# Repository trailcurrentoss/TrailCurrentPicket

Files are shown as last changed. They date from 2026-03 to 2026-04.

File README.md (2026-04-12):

# TrailCurrent Picket

Sensor module that monitors cabinet and door open/closed states using reed switches and reports status over a CAN bus interface. Part of the [TrailCurrent](https://trailcurrent.com) open-source vehicle platform.

## Hardware Overview

- **Board:** [Waveshare ESP32-S3-RS485-CAN](https://www.waveshare.com/esp32-s3-rs485-can.htm)
- **Microcontroller:** ESP32-S3
- **Framework:** ESP-IDF
- **Function:** Cabinet and door state monitoring with CAN bus reporting
- **Key Features:**
  - 13 reed switch inputs for open/closed detection
  - CAN bus communication at 500 kbps (onboard TJA1051 transceiver)
  - Firmware-configurable CAN address via NVS (up to 8 modules per bus)
  - Over-the-air (OTA) firmware updates via WiFi (triggered over CAN)
  - Onboard status LED
  - Custom flash partition layout with dual OTA slots

### Design Specifications

- **Operating Temperature:** -20°C to +70°C
- **Power:** 7-36V DC input via onboard buck converter
- **Data Rate:** 5 transmissions per second

## CAN Bus Addressing

The CAN message ID is set at compile time via the `PICKET_ADDRESS` build flag. Valid values are **0 through 7**, giving 8 possible modules on the same bus. The CAN ID is computed as `0x0A + PICKET_ADDRESS`. Default is 0 if not specified. The build will fail if a value outside 0-7 is used.

```bash
# Build with default address 0 (CAN ID 0x0A)
idf.py build

# Build for address 3 (CAN ID 0x0D)
idf.py build -DPICKET_ADDRESS=3
```

| `PICKET_ADDRESS` | CAN ID | DBC Message Name |
|---|---|---|
| 0 (default) | 0x0A | PicketStatus0 |
| 1 | 0x0B | PicketStatus1 |
| 2 | 0x0C | PicketStatus2 |
| 3 | 0x0D | PicketStatus3 |
| 4 | 0x0E | PicketStatus4 |
| 5 | 0x0F | PicketStatus5 |
| 6 | 0x10 | PicketStatus6 |
| 7 | 0x11 | PicketStatus7 |

#### Building All Variants

Use `build-all.sh` to build all 8 address variants in a single run:

```bash
./build-all.sh
```

This produces:

```
build/picket_addr0.bin   # Address 0 (CAN ID 0x0A)
build/picket_addr1.bin   # Address 1 (CAN ID 0x0B)
...
build/picket_addr7.bin   # Address 7 (CAN ID 0x11)
```

#### Creating a GitHub Release

After building all variants, upload all 8 binaries as release assets:

```bash
git tag -a v1.0.0 -m "Firmware release v1.0.0"
git push origin v1.0.0

gh release create v1.0.0 \
  build/picket_addr0.bin \
  build/picket_addr1.bin \
  build/picket_addr2.bin \
  build/picket_addr3.bin \
  build/picket_addr4.bin \
  build/picket_addr5.bin \
  build/picket_addr6.bin \
  build/picket_addr7.bin \
  --repo trailcurrentoss/TrailCurrentPicket \
  --title "v1.0.0" \
  --notes "Firmware release v1.0.0"
```

The Headwaters deployment system and the web-based firmware installer both expect these 8 files per release. The naming convention `{type}_addr{N}.bin` is required.

### CAN Message Format

Each module transmits a 2-byte message at 5 Hz (200 ms interval):

| Byte | Bits  | Description |
|---|---|---|
| 0 | 0-7 | Door status 1-8 (RSW01-RSW08) |
| 1 | 0-4 | Door status 9-13 (RSW09-RSW13) |
| 1 | 5-7 | Reserved |

Each bit represents one reed switch: `1` = door open, `0` = door closed.

### CAN Control Messages

The module also listens for control messages from other nodes:

- **CAN ID 0x00 - OTA Update Notification:** Contains a 3-byte MAC address suffix. If it matches this module's hostname, the module connects to WiFi using stored credentials and enters OTA update mode.
- **CAN ID 0x01 - WiFi Credential Configuration:** Multi-message protocol to receive and store WiFi SSID and password in NVS flash for future OTA updates.
- **CAN ID 0x02 - Discovery Trigger:** Broadcast with no payload. Unconfigured modules respond by joining WiFi and advertising via mDNS for Headwaters to discover and register them.
- **CAN ID 0x03 - Discovery Reset:** Targeted by MAC address. Clears the configured flag so the module responds to the next discovery trigger.
- **CAN ID 0x04 - Firmware Version Report:** Sent once on boot. Payload: `[mac3, mac4, mac5, major, minor, patch]`. Reports running firmware version to Headwaters.

### Module Discovery

New modules are automatically discovered by Headwaters using a one-at-a-time registration protocol:

1. Headwaters sends CAN ID 0x02 (broadcast, no payload)
2. Unconfigured modules join WiFi and advertise `_trailcurrent._tcp` via mDNS with TXT records: `type`, `addr`, `canid`, `fw`
3. Headwaters browses mDNS, reads the metadata, and sends `GET /discovery/confirm`
4. Module marks itself configured in NVS and tears down WiFi

The discovery window is 30 seconds. The status LED blinks at 4 Hz during discovery. Already-configured modules ignore the trigger. To re-discover a module, send CAN ID 0x03 with its MAC bytes to clear the configured flag.

### Firmware Version

The firmware version is set in `CMakeLists.txt` via `PROJECT_VER` and reported during discovery via the `fw` mDNS TXT record. It is also available at runtime via `esp_app_get_description()`.

## GPIO Pin Assignments

### Onboard (not on pin header)

| GPIO | Function | Notes |
|---|---|---|
| 0 | Status LED | Onboard LED |
| 15 | CAN TX | Onboard TJA1051 transceiver |
| 16 | CAN RX | Onboard TJA1051 transceiver |
| 19 | USB D_N | USB Serial/JTAG (flash + monitor) |
| 20 | USB D_P | USB Serial/JTAG (flash + monitor) |

### Pin Header (reed switch inputs)

| GPIO | Function | Notes |
|---|---|---|
| 4 | RSW01 | Internal pull-up, no ext. resistor |
| 5 | RSW02 | Internal pull-up, no ext. resistor |
| 6 | RSW03 | Internal pull-up, no ext. resistor |
| 7 | RSW04 | Internal pull-up, no ext. resistor |
| 8 | RSW05 | Internal pull-up, no ext. resistor |
| 9 | RSW06 | Internal pull-up, no ext. resistor |
| 10 | RSW07 | Internal pull-up, no ext. resistor |
| 11 | RSW08 | Internal pull-up, no ext. resistor |
| 12 | RSW09 | Internal pull-up, no ext. resistor |
| 13 | RSW10 | Internal pull-up, no ext. resistor |
| 14 | RSW11 | Internal pull-up, no ext. resistor |
| 43 | RSW12 | Internal pull-up, no ext. resistor |
| 44 | RSW13 | Internal pull-up, no ext. resistor |

## Hardware Requirements

### Components

- **Board:** [Waveshare ESP32-S3-RS485-CAN](https://www.waveshare.com/esp32-s3-rs485-can.htm) — industrial-grade board with onboard CAN transceiver, buck converter (7-36V input), and pin header for sensor connections
- **Sensors:** Normally Open (NO) reed switches
- **Connectors:** Wire to pin header (2x10, 2.54mm pitch)

### KiCAD Library Dependencies

This project uses the consolidated [TrailCurrentKiCADLibraries](https://github.com/trailcurrentoss/TrailCurrentKiCADLibraries).

**Setup:**

```bash
# Clone the library alongside this project
git clone git@github.com:trailcurrentoss/TrailCurrentKiCADLibraries.git

# Set environment variables (add to ~/.bashrc or ~/.zshrc)
# Adjust paths to where you cloned the library
export TRAILCURRENT_SYMBOL_DIR="../TrailCurrentKiCADLibraries/symbols"
export TRAILCURRENT_FOOTPRINT_DIR="../TrailCurrentKiCADLibraries/footprints"
export TRAILCURRENT_3DMODEL_DIR="../TrailCurrentKiCADLibraries/3d_models"
```

See [KICAD_ENVIRONMENT_SETUP.md](https://github.com/trailcurrentoss/TrailCurrentKiCADLibraries/blob/main/KICAD_ENVIRONMENT_SETUP.md) in the library repository for detailed setup instructions.

## Firmware

The firmware is built with ESP-IDF (not PlatformIO/Arduino).

### Build & Flash

```bash
# Source ESP-IDF environment
source ~/esp/v5.5.2/esp-idf/export.sh

# Set target (first time only)
idf.py set-target esp32s3

# Build (default address 0, CAN ID 0x0A)
idf.py build

# Build with a specific module address (0-7)
idf.py build -DPICKET_ADDRESS=3

# Flash via USB
idf.py -p /dev/ttyACM0 flash

# Monitor serial output
idf.py -p /dev/ttyACM0 monitor
```

### OTA Update

```bash
# Use the binary matching the module's address
curl -X POST http://esp32-XXYYZZ.local/ota --data-binary @build/picket_addr0.bin
```

Where `XXYYZZ` is the last 3 bytes of the device's WiFi MAC address (printed at boot).

## Opening the Project

1. **Set up environment variables** (see Library Dependencies above)
2. **Open KiCAD:**
   ```bash
   kicad EDA/TrailCurrentPicketModule/TrailCurrentPicketModule.kicad_pro
   ```
3. **Verify libraries load** - All symbol and footprint libraries should resolve without errors
4. **View 3D models** - Open PCB and press `Alt+3` to view the 3D visualization

## Manufacturing

- **PCB Files:** Ready for fabrication via standard PCB services (JLCPCB, OSH Park, etc.)
- **BOM Generation:** Export BOM from KiCAD schematic (Tools > Generate BOM)
- **Enclosure:** FreeCAD design included in `CAD/` directory
- **JLCPCB Assembly:** See [BOM_ASSEMBLY_WORKFLOW.md](https://github.com/trailcurrentoss/TrailCurrentKiCADLibraries/blob/main/BOM_ASSEMBLY_WORKFLOW.md) for detailed assembly workflow

## Documentation

- **Requirements:** See `DOCS/Requirements/high-level-requirements.md` for detailed specifications

## Project Structure

```
├── CAD/                          # FreeCAD enclosure design
├── DOCS/                         # Requirements documentation
│   └── Requirements/
│       └── high-level-requirements.md
├── EDA/                          # KiCAD hardware design files
│   └── TrailCurrentPicketModule/
│       ├── *.kicad_pro           # KiCAD project
│       ├── *.kicad_sch           # Schematic
│       └── *.kicad_pcb           # PCB layout
├── main/                         # ESP-IDF firmware source
│   ├── main.c                    # Main application, CAN task, reed switch reading
│   ├── discovery.h / discovery.c # mDNS self-discovery and Headwaters registration
│   ├── ota.h / ota.c             # OTA firmware updates via WiFi
│   ├── wifi_config.h / .c        # WiFi credential storage and CAN provisioning
│   ├── CMakeLists.txt            # Component build config
│   └── idf_component.yml         # Component dependencies
├── CMakeLists.txt                # ESP-IDF project root
├── partitions.csv                # Flash partition layout
├── build-all.sh                  # Build all 8 address variants (addr 0-7)
└── sdkconfig.defaults            # Default build configuration
```

## License

MIT License - See LICENSE file for details.

This is open source hardware. You are free to use, modify, and distribute these designs for personal or commercial purposes.

## Contributing

Improvements and contributions are welcome! Please submit issues or pull requests.

## Support

For questions about:
- **KiCAD setup:** See [KICAD_ENVIRONMENT_SETUP.md](https://github.com/trailcurrentoss/TrailCurrentKiCADLibraries/blob/main/KICAD_ENVIRONMENT_SETUP.md)
- **Assembly workflow:** See [BOM_ASSEMBLY_WORKFLOW.md](https://github.com/trailcurrentoss/TrailCurrentKiCADLibraries/blob/main/BOM_ASSEMBLY_WORKFLOW.md)

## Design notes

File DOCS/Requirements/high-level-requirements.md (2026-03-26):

# High-Level Design (HLD) Document

## 1. Project Overview

**Project Title:** Picket Module

**Description:** A microcontroller-based system that monitors the status of doors and cabinets. It will be used to make the high level system contextually aware of which doors and or cabinets are currently open or closed.

**Objective:**
To design and implement a reliable, low-power, and cost-effective microcontroller-based system for door and cabinet status monitoring that can operate autonomously and send data over the CAN bus.

---

## 2. Microcontroller Selection

**Selected Microcontroller:**
**ESP32-S3** (Waveshare ESP32-S3-RS485-CAN)
[Datasheet](https://www.espressif.com/sites/default/files/documentation/esp32-s3_datasheet_en.pdf)

**Rationale for Selection:**
- Off-the-shelf board with onboard CAN transceiver (TJA1051), buck converter (7-36V), and 20-pin header for sensor connections.
- 13 GPIOs available on pin header with internal pull-ups — no external resistors needed.
- Strong ecosystem and ESP-IDF development support.
- Shared board with Solstice module, reducing BOM complexity.

---

## 3. System Requirements

### 3.1 Functional Requirements

| Requirement | Description |
|---|---|
| Door Sensing | Read and send over CAN bus the door or cabinet status |
| Data Transmission | Send collected data to the rest of the network via CAN protocol |
| Power Management | Support for low-power modes to reduce load on installed environment |

### 3.2 Non-Functional Requirements

| Requirement | Description |
|---|---|
| Reliability | System must operate continuously without disruption indefinitely for solar installs |
| CAN Bus Data Usage | **Needs calculation to see what is available on a 500k CAN Bus.** |
| Environmental Tolerance | Operate within -20°C to +70°C |
| Cost | Target cost < $5 per unit |
---

## 4. System Architecture Overview

### 4.1 Hardware Components

| Component | Description |
|---|---|
| ESP32-S3 (Waveshare ESP32-S3-RS485-CAN) | Main microcontroller with onboard CAN transceiver |
| Reed Swith | Any brand should suffice, justt needs to provide an on/off state to trigger correctly. |

### 4.2 Software Components

| Component | Description |
|---|---|
| Main Application | Main data collection, and transmission |
| Sensor Drivers | Interface with reed switches |
| Communication Stack | CAN Bus coomunication implementation |
| OTA | Over the air update capabilities with trigger coming from CAN Bus. |

---

## 5. Communication Protocol

- **CAN Bus:** CAN Bus protocol used to transmit data  
- **Data Format:** Binary representation of each sensor status
- **Transmission Frequency:** 5 times per second to avoid delayed notification of doors changing status during travel.
---

## 6. Power Management Strategy

- **Battery:** Connected to house battery of implemented vehicle.
- **Power Supply Circuit:** 5V DC to DC buck converter with 3.3V regulator (e.g., AMS1117)  
---

## 7. Development Tools and Environment

| Tool | Description |
|---|---|
| ESP-IDF | Development framework (v5.5.2) |
| VS Code | Development IDE |
| KiCAD | EDA Design tool for schematic and PCB |
| FreeCAD | CAD tool used for enclosure design |
| Version Control | Git with GitHub for repo and source control |
| Documentation Tools | Markdown |

---

## 8. Testing and Validation

| Test Type | Description |
|---|---|
| Unit Testing | Test individual modules (e.g., sensor drivers, communication stack) |
| Integration Testing | Ensure all components work together as expected |
| Performance Testing | Measure power consumption, response time, and data accuracy |
---

## 9. Future Enhancements

- Add GPS module for location tracking  
- Support for multiple sensors (e.g., PM2.5, CO2)  
- Edge computing for local data processing  
- Integration with IoT platforms (e.g., AWS IoT, Azure IoT Hub)  
- Mobile app integration for real-time monitoring

---

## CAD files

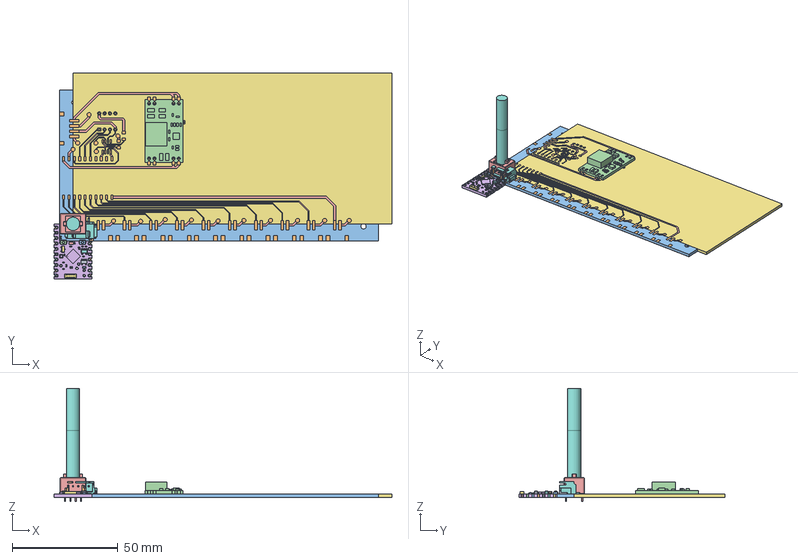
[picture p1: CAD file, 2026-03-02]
CAD/TrailCurrentPicketModuleEDA.FCStd
159.8 x 97.6 x 53.6 mm
Model-TrailCurrentCabinetAndDoorSensorModule
SxB-XH-SM4-TB
SxB-XH-SM4-TB001
SxB-XH-SM4-TB002
BODY-SO
LEAD-D0008A
LEAD-D0008A001
LEAD-D0008A002
LEAD-D0008A003
LEAD-D0008A004
LEAD-D0008A005
LEAD-D0008A006
LEAD-D0008A007
PCB
USB_C_Receptacle_16P_TopMnt_Horizontal_GCT_USB4105-xx-A037
USB_C_Receptacle_16P_TopMnt_Horizontal_GCT_USB4105-xx-A038
USB_C_Receptacle_16P_TopMnt_Horizontal_GCT_USB4105-xx-A039
USB_C_Receptacle_16P_TopMnt_Horizontal_GCT_USB4105-xx-A040
USB_C_Receptacle_16P_TopMnt_Horizontal_GCT_USB4105-xx-A041
USB_C_Receptacle_16P_TopMnt_Horizontal_GCT_USB4105-xx-A042
USB_C_Receptacle_16P_TopMnt_Horizontal_GCT_USB4105-xx-A043
USB_C_Receptacle_16P_TopMnt_Horizontal_GCT_USB4105-xx-A044
USB_C_Receptacle_16P_TopMnt_Horizontal_GCT_USB4105-xx-A045
USB_C_Receptacle_16P_TopMnt_Horizontal_GCT_USB4105-xx-A046
USB_C_Receptacle_16P_TopMnt_Horizontal_GCT_USB4105-xx-A047
USB_C_Receptacle_16P_TopMnt_Horizontal_GCT_USB4105-xx-A048
USB_C_Receptacle_16P_TopMnt_Horizontal_GCT_USB4105-xx-A049
USB_C_Receptacle_16P_TopMnt_Horizontal_GCT_USB4105-xx-A050
USB_C_Receptacle_16P_TopMnt_Horizontal_GCT_USB4105-xx-A051
USB_C_Receptacle_16P_TopMnt_Horizontal_GCT_USB4105-xx-A052
USB_C_Receptacle_16P_TopMnt_Horizontal_GCT_USB4105-xx-A053
USB_C_Receptacle_16P_TopMnt_Horizontal_GCT_USB4105-xx-A054
USB_C_Receptacle_16P_TopMnt_Horizontal_GCT_USB4105-xx-A055
USB_C_Receptacle_16P_TopMnt_Horizontal_GCT_USB4105-xx-A056
USB_C_Receptacle_16P_TopMnt_Horizontal_GCT_USB4105-xx-A057
USB_C_Receptacle_16P_TopMnt_Horizontal_GCT_USB4105-xx-A058
USB_C_Receptacle_16P_TopMnt_Horizontal_GCT_USB4105-xx-A059
USB_C_Receptacle_16P_TopMnt_Horizontal_GCT_USB4105-xx-A060
USB_C_Receptacle_16P_TopMnt_Horizontal_GCT_USB4105-xx-A061
USB_C_Receptacle_16P_TopMnt_Horizontal_GCT_USB4105-xx-A062
USB_C_Receptacle_16P_TopMnt_Horizontal_GCT_USB4105-xx-A063
USB_C_Receptacle_16P_TopMnt_Horizontal_GCT_USB4105-xx-A064
USB_C_Receptacle_16P_TopMnt_Horizontal_GCT_USB4105-xx-A065
USB_C_Receptacle_16P_TopMnt_Horizontal_GCT_USB4105-xx-A066
USB_C_Receptacle_16P_TopMnt_Horizontal_GCT_USB4105-xx-A067
USB_C_Receptacle_16P_TopMnt_Horizontal_GCT_USB4105-xx-A068
USB_C_Receptacle_16P_TopMnt_Horizontal_GCT_USB4105-xx-A069
USB_C_Receptacle_16P_TopMnt_Horizontal_GCT_USB4105-xx-A070
USB_C_Receptacle_16P_TopMnt_Horizontal_GCT_USB4105-xx-A071
USB_C_Receptacle_16P_TopMnt_Horizontal_GCT_USB4105-xx-A072
Button_black_002
Button_black_003
io23
io21
io22
io12
io13
Corps
Corps001
Corps002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

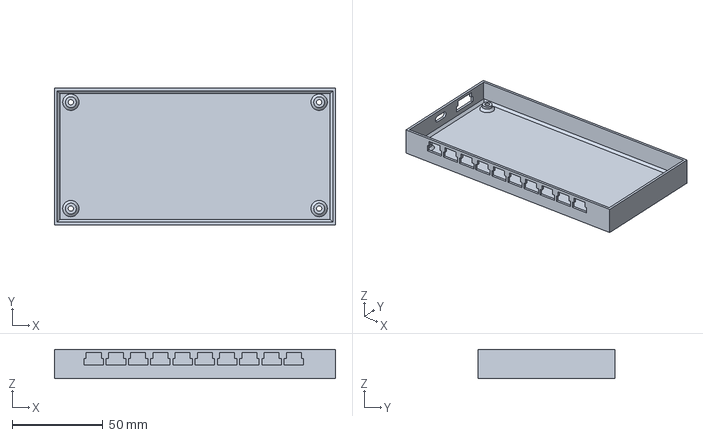
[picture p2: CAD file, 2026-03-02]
CAD/TrailCurrentPicketModuleHousing.FCStd
154.8 x 75.2 x 16.0 mm

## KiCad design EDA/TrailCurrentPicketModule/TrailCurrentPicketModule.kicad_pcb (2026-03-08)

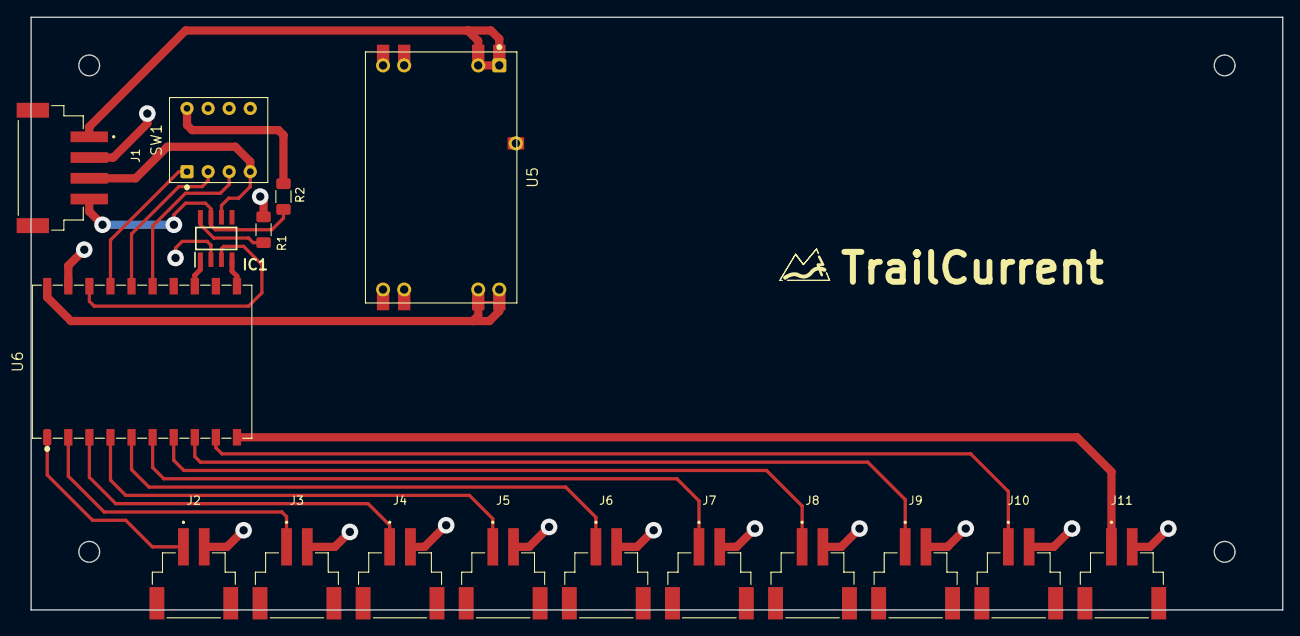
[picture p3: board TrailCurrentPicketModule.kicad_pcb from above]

Board: 2 copper layers, 150.8 x 71.4 mm, 19 parts (0 on the bottom side), 23 nets.

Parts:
IC1: SN65HVD230DR
J1: S4B-XH-SM4-TB; JST_S4B-XH-SM4-TB
J2, J3, J4, J5, J6, J7, J8, J9, J10, J11: S2B-XH-SM4-TB; JST_S2B-XH-SM4-TB
LOGO: TrailCurrentLogo_Text
LOGO#2: TrailCurrentLogo_Icon
R1: 10k; R_1206_3216Metric_Pad1.30x1.75mm_HandSolder
R2: 120; R_1206_3216Metric_Pad1.30x1.75mm_HandSolder
SW1: DS-04
U5: Mini560
U6: ESP32-C6-SuperMini; ESP32-C6-SuperMini_SMD

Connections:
+3.3V: IC1.3 (VCC), U6.13 (3V3)
+5V: U5.8 (VOUT+), U5.9 (VOUT+), U6.11 (5V)
+12V: J1.1, U5.1 (VIN+), U5.2 (VIN+)
ADDR01: SW1.3, U6.16 (GPIO18)
ADDR02: SW1.2, U6.15 (GPIO19)
ADDR03: SW1.1, U6.14 (GPIO20)
CANH: IC1.7 (CANH), J1.4, R2.1
CANL: IC1.6 (CANL), J1.3, SW1.4
CAN_RX: IC1.4 (R), U6.20 (GPIO8)
CAN_TX: IC1.1 (D), U6.18 (GPIO14)
GND: IC1.2 (GND), J1.2, J2.2, J3.2, J4.2, J5.2, J6.2, J7.2, J8.2, J9.2, J10.2, J11.2, R1.1, SW1.5, SW1.6, SW1.7, U5.3 (GND), U5.4 (GND), U5.6 (GND), U5.7 (GND), U6.12 (GND)
unnamed: IC1.8 (RS), R1.2
unnamed: R2.2, SW1.8
RSW01: J2.1, U6.1 (TX)
RSW02: J3.1, U6.2 (RX)
RSW03: J4.1, U6.3 (GPIO0)
RSW04: J5.1, U6.4 (GPIO1)
RSW05: J6.1, U6.5 (GPIO2)
RSW06: J7.1, U6.6 (GPIO3)
RSW07: J8.1, U6.7 (GPIO4)
RSW08: J9.1, U6.8 (GPIO5)
RSW09: J10.1, U6.9 (GPIO6)
RSW10: J11.1, U6.10 (GPIO7)

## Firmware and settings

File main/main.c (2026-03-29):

#include <stdio.h>
#include <string.h>
#include "freertos/FreeRTOS.h"
#include "freertos/task.h"
#include "driver/gpio.h"
#include "driver/twai.h"
#include "esp_log.h"
#include "esp_timer.h"
#include "esp_app_desc.h"
#include "esp_mac.h"
#include "wifi_config.h"
#include "ota.h"
#include "discovery.h"

static const char *TAG = "picket";

// =============================================================================
// Pin Definitions — Waveshare ESP32-S3-RS485-CAN pin header
// =============================================================================

// CAN bus pins (onboard TJA1051 transceiver, not on pin header)
#define CAN_TX_PIN   15
#define CAN_RX_PIN   16

// Status LED (onboard LED on GPIO0)
#define STATUS_LED_PIN  0

// Reed switch inputs (Normally Open — close when magnet nearby / door closed)
// HIGH = door open, LOW = door closed (using internal pull-ups)
static const gpio_num_t RSW_PINS[] = {
    GPIO_NUM_4,   // RSW01
    GPIO_NUM_5,   // RSW02
    GPIO_NUM_6,   // RSW03
    GPIO_NUM_7,   // RSW04
    GPIO_NUM_8,   // RSW05
    GPIO_NUM_9,   // RSW06
    GPIO_NUM_10,  // RSW07
    GPIO_NUM_11,  // RSW08
    GPIO_NUM_12,  // RSW09
    GPIO_NUM_13,  // RSW10
    GPIO_NUM_14,  // RSW11
    GPIO_NUM_43,  // RSW12
    GPIO_NUM_44,  // RSW13
};
#define NUM_RSW (sizeof(RSW_PINS) / sizeof(RSW_PINS[0]))

// =============================================================================
// CAN Bus Configuration
// =============================================================================

// CAN protocol IDs
#define CAN_ID_OTA              0x00
#define CAN_ID_WIFI_CONFIG      0x01
#define CAN_ID_DISCOVERY_TRIGGER 0x02

// CAN IDs 0x0A-0x11 reserved for up to 8 Picket modules.
// Set address at build time: idf.py build -DPICKET_ADDRESS=3
#define CAN_BASE_ID     0x0A
#define CAN_BAUDRATE    500000

#ifndef PICKET_ADDRESS
#define PICKET_ADDRESS  0
#endif
#if PICKET_ADDRESS < 0 || PICKET_ADDRESS > 7
#error "PICKET_ADDRESS must be 0-7"
#endif

// Transmit interval (200 ms = 5 Hz)
#define TX_INTERVAL_MS  200
#define TX_PROBE_INTERVAL_MS  2000 // slow probe when no peers detected

// Debounce time for reed switch readings
#define DEBOUNCE_MS     50

// =============================================================================
// Global State
// =============================================================================

static const uint32_t s_can_message_id = CAN_BASE_ID + PICKET_ADDRESS;

// Debounced reed switch state
static volatile uint16_t s_debounced_state = 0;

// =============================================================================
// Reed Switch Reading
// =============================================================================

static uint16_t read_reed_switches(void)
{
    uint16_t state = 0;
    for (int i = 0; i < NUM_RSW; i++) {
        // HIGH = door open (pull-up, NO reed switch open)
        // LOW = door closed (reed switch closed by magnet)
        if (gpio_get_level(RSW_PINS[i]) == 1) {
            state |= (1 << i);
        }
    }
    return state;
}

// =============================================================================
// TWAI (CAN) task — runs independently (pattern from Solstice)
// =============================================================================

static void twai_task(void *arg)
{
    twai_general_config_t g_config = TWAI_GENERAL_CONFIG_DEFAULT(
        (gpio_num_t)CAN_TX_PIN, (gpio_num_t)CAN_RX_PIN, TWAI_MODE_NORMAL);
    twai_timing_config_t t_config = TWAI_TIMING_CONFIG_500KBITS();
    twai_filter_config_t f_config = TWAI_FILTER_CONFIG_ACCEPT_ALL();

    if (twai_driver_install(&g_config, &t_config, &f_config) != ESP_OK) {
        ESP_LOGE(TAG, "Failed to install TWAI driver");
        vTaskDelete(NULL);
        return;
    }
    if (twai_start() != ESP_OK) {
        ESP_LOGE(TAG, "Failed to start TWAI driver");
        vTaskDelete(NULL);
        return;
    }

    // Broadcast firmware version on CAN 0x04 at startup
    {
        uint8_t mac[6];
        esp_read_mac(mac, ESP_MAC_WIFI_STA);
        const esp_app_desc_t *app = esp_app_get_description();
        unsigned maj = 0, min = 0, pat = 0;
        sscanf(app->version, "%u.%u.%u", &maj, &min, &pat);
        twai_message_t ver_msg = {
            .identifier = 0x04,
            .data_length_code = 6,
            .data = { mac[3], mac[4], mac[5], maj, min, pat }
        };
        twai_transmit(&ver_msg, pdMS_TO_TICKS(50));
        ESP_LOGI(TAG, "Version broadcast: %s (CAN 0x04)", app->version);
    }

    uint32_t alerts = TWAI_ALERT_RX_DATA | TWAI_ALERT_ERR_PASS |
                      TWAI_ALERT_BUS_ERROR | TWAI_ALERT_RX_QUEUE_FULL |
                      TWAI_ALERT_BUS_OFF | TWAI_ALERT_BUS_RECOVERED |
                      TWAI_ALERT_ERR_ACTIVE | TWAI_ALERT_TX_FAILED |
                      TWAI_ALERT_TX_SUCCESS;
    twai_reconfigure_alerts(alerts, NULL);
    ESP_LOGI(TAG, "TWAI driver started (NORMAL mode)");

    typedef enum { TX_ACTIVE, TX_PROBING } tx_state_t;
    bool bus_off = false;
    tx_state_t tx_state = TX_ACTIVE;
    int tx_fail_count = 0;
    const int TX_FAIL_THRESHOLD = 3;
    int64_t last_tx_us = 0;
    const int64_t tx_period_us = TX_INTERVAL_MS * 1000LL;
    const int64_t tx_probe_period_us = TX_PROBE_INTERVAL_MS * 1000LL;

    // Debounce state (owned by this task)
    uint16_t last_raw_state = read_reed_switches();
    uint16_t debounced = last_raw_state;
    int64_t last_change_us = esp_timer_get_time();

    while (1) {
        uint32_t triggered;
        twai_read_alerts(&triggered, pdMS_TO_TICKS(10));

        // --- Bus error handling ---
        if (triggered & TWAI_ALERT_BUS_OFF) {
            ESP_LOGE(TAG, "TWAI bus-off, initiating recovery");
            bus_off = true;
            twai_initiate_recovery();
            continue;
        }
        if (triggered & TWAI_ALERT_BUS_RECOVERED) {
            ESP_LOGI(TAG, "TWAI bus recovered, restarting");
            twai_start();
            bus_off = false;
            tx_fail_count = 0;
            tx_state = TX_PROBING;
        }
        if (triggered & TWAI_ALERT_ERR_PASS) {
            ESP_LOGW(TAG, "TWAI error passive (no peers ACKing?)");
        }
        if (triggered & TWAI_ALERT_TX_FAILED) {
            if (tx_state == TX_ACTIVE) {
                tx_fail_count++;
                if (tx_fail_count >= TX_FAIL_THRESHOLD) {
                    tx_state = TX_PROBING;
                    ESP_LOGW(TAG, "TWAI no peers detected, entering slow probe");
                }
            }
        }
        if (triggered & TWAI_ALERT_TX_SUCCESS) {
            if (tx_state == TX_PROBING) {
                tx_state = TX_ACTIVE;
                tx_fail_count = 0;
                ESP_LOGI(TAG, "TWAI probe ACK'd, peer detected, resuming normal TX");
            }
            tx_fail_count = 0;
        }

        // --- Drain received messages ---
        if (triggered & TWAI_ALERT_RX_DATA) {
            if (tx_state == TX_PROBING) {
                tx_state = TX_ACTIVE;
                tx_fail_count = 0;
                ESP_LOGI(TAG, "TWAI peer detected via RX, resuming normal TX");
            }
            twai_message_t msg;
            while (twai_receive(&msg, 0) == ESP_OK) {
                if (msg.rtr) continue;

                switch (msg.identifier) {
                case CAN_ID_OTA:
                    if (msg.data_length_code >= 3) {
                        ota_handle_trigger(msg.data, msg.data_length_code);
                    }
                    break;

                case CAN_ID_WIFI_CONFIG:
                    if (msg.data_length_code >= 1) {
                        wifi_config_handle_can(msg.data, msg.data_length_code);
                    }
                    break;

                case CAN_ID_DISCOVERY_TRIGGER:
                    discovery_handle_trigger();
                    break;

                default:
                    break;
                }
            }
        }

        // Check wifi config timeout
        wifi_config_check_timeout();

        // --- Debounce reed switches ---
        uint16_t raw = read_reed_switches();
        int64_t now_us = esp_timer_get_time();

        if (raw != last_raw_state) {
            last_raw_state = raw;
            last_change_us = now_us;
        }
        if ((now_us - last_change_us) >= ((int64_t)DEBOUNCE_MS * 1000)) {
            debounced = last_raw_state;
        }
        s_debounced_state = debounced;

        // --- Periodic transmit ---
        int64_t effective_period = (tx_state == TX_PROBING) ? tx_probe_period_us : tx_period_us;
        if (!bus_off && (now_us - last_tx_us >= effective_period)) {
            last_tx_us = now_us;

            twai_message_t tx_msg = {
                .identifier = s_can_message_id,
                .data_length_code = 2,
                .data = {
                    (uint8_t)(debounced & 0xFF),         // RSW01-RSW08
                    (uint8_t)((debounced >> 8) & 0x1F),  // RSW09-RSW13
                }
            };
            twai_transmit(&tx_msg, 0);
        }
    }
}

// =============================================================================
// Main application
// =============================================================================

void app_main(void)
{
    ESP_LOGI(TAG, "=== TrailCurrent Picket ===");

    // Initialize NVS and load WiFi credentials
    ESP_ERROR_CHECK(wifi_config_init());

    char ssid[33] = {0};
    char password[64] = {0};
    if (wifi_config_load(ssid, sizeof(ssid), password, sizeof(password))) {
        ESP_LOGI(TAG, "WiFi credentials loaded from NVS");
    } else {
        ESP_LOGI(TAG, "No WiFi credentials — OTA disabled until provisioned via CAN");
    }

    // Initialize discovery and OTA (must be after wifi_config_init)
    discovery_init();
    ota_init();

    ESP_LOGI(TAG, "Hostname: %s", wifi_config_get_hostname());

    // Configure status LED
    gpio_config_t led_cfg = {
        .pin_bit_mask = (1ULL << STATUS_LED_PIN),
        .mode = GPIO_MODE_OUTPUT,
    };
    gpio_config(&led_cfg);
    gpio_set_level(STATUS_LED_PIN, 1);

    // Configure reed switch inputs with internal pull-ups
    for (int i = 0; i < NUM_RSW; i++) {
        gpio_config_t io_cfg = {
            .pin_bit_mask = (1ULL << RSW_PINS[i]),
            .mode = GPIO_MODE_INPUT,
            .pull_up_en = GPIO_PULLUP_ENABLE,
            .pull_down_en = GPIO_PULLDOWN_DISABLE,
        };
        gpio_config(&io_cfg);
    }
    ESP_LOGI(TAG, "Configured %d reed switch inputs", NUM_RSW);

    ESP_LOGI(TAG, "Module address: %d, CAN ID: 0x%02X", PICKET_ADDRESS, (unsigned)s_can_message_id);

    // CAN runs in its own task so bus errors never block app_main
    xTaskCreatePinnedToCore(twai_task, "twai", 4096, NULL, 5, NULL, 1);

    ESP_LOGI(TAG, "=== Setup Complete ===");

    // Main task has nothing else to do — park it
    while (1) {
        vTaskDelay(pdMS_TO_TICKS(1000));
    }
}

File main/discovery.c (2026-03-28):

#include "discovery.h"
#include "wifi_config.h"
#include "ota.h"

#include <string.h>
#include <stdio.h>
#include "freertos/FreeRTOS.h"
#include "freertos/task.h"
#include "esp_log.h"
#include "esp_app_desc.h"
#include "esp_http_server.h"
#include "esp_timer.h"
#include "mdns.h"
#include "driver/gpio.h"

static const char *TAG = "discovery";

// ---------------------------------------------------------------------------
// Compile-time module identity
// ---------------------------------------------------------------------------

#ifndef MODULE_TYPE
#error "MODULE_TYPE must be defined (e.g., \"picket\")"
#endif

#ifndef PICKET_ADDRESS
#define PICKET_ADDRESS 0
#endif

#define CAN_BASE_ID 0x0A

// ---------------------------------------------------------------------------
// Discovery state
// ---------------------------------------------------------------------------

static volatile bool s_confirmed = false;
static volatile bool s_discovery_running = false;

// ---------------------------------------------------------------------------
// Status LED blink (GPIO0, 4 Hz)
// ---------------------------------------------------------------------------

#define STATUS_LED_PIN 0

static esp_timer_handle_t s_led_timer = NULL;
static bool s_led_state = false;

static void led_blink_cb(void *arg)
{
    s_led_state = !s_led_state;
    gpio_set_level(STATUS_LED_PIN, s_led_state ? 1 : 0);
}

static void led_blink_start(void)
{
    esp_timer_create_args_t args = {
        .callback = led_blink_cb,
        .name = "disc_led",
    };
    esp_timer_create(&args, &s_led_timer);
    esp_timer_start_periodic(s_led_timer, 125000);  // 125 ms = 4 Hz
}

static void led_blink_stop(void)
{
    if (s_led_timer) {
        esp_timer_stop(s_led_timer);
        esp_timer_delete(s_led_timer);
        s_led_timer = NULL;
    }
    gpio_set_level(STATUS_LED_PIN, 1);  // restore solid on
}

// ---------------------------------------------------------------------------
// mDNS service advertisement with TXT records
// ---------------------------------------------------------------------------

static void discovery_mdns_start(void)
{
    const char *hostname = wifi_config_get_hostname();

    char addr_str[4];
    char canid_str[8];
    snprintf(addr_str, sizeof(addr_str), "%d", PICKET_ADDRESS);
    snprintf(canid_str, sizeof(canid_str), "0x%02X", CAN_BASE_ID + PICKET_ADDRESS);

    const esp_app_desc_t *app = esp_app_get_description();

    mdns_init();
    mdns_hostname_set(hostname);
    mdns_instance_name_set("TrailCurrent Module");

    mdns_txt_item_t txt[] = {
        { "type",  MODULE_TYPE },
        { "addr",  addr_str },
        { "canid", canid_str },
        { "fw",    app->version },
    };

    mdns_service_add("TrailCurrent Discovery", "_trailcurrent", "_tcp",
                     80, txt, sizeof(txt) / sizeof(txt[0]));

    ESP_LOGI(TAG, "mDNS discovery: %s.local type=%s addr=%s canid=%s fw=%s",
             hostname, MODULE_TYPE, addr_str, canid_str, app->version);
}

// ---------------------------------------------------------------------------
// HTTP confirmation endpoint — Headwaters calls this to acknowledge
// ---------------------------------------------------------------------------

static esp_err_t confirm_handler(httpd_req_t *req)
{
    ESP_LOGI(TAG, "Discovery confirmed by Headwaters");
    httpd_resp_sendstr(req, "confirmed\n");
    s_confirmed = true;
    return ESP_OK;
}

static httpd_handle_t discovery_start_server(void)
{
    httpd_config_t config = HTTPD_DEFAULT_CONFIG();
    httpd_handle_t server = NULL;

    if (httpd_start(&server, &config) != ESP_OK) {
        ESP_LOGE(TAG, "Failed to start HTTP server");
        return NULL;
    }

    httpd_uri_t confirm_uri = {
        .uri     = "/discovery/confirm",
        .method  = HTTP_GET,
        .handler = confirm_handler,
    };
    httpd_register_uri_handler(server, &confirm_uri);

    return server;
}

// ---------------------------------------------------------------------------
// Public API
// ---------------------------------------------------------------------------

void discovery_init(void)
{
    ESP_LOGI(TAG, "Discovery ready — will respond to CAN 0x02 trigger");
}

static void discovery_task_fn(void *arg)
{
    if (!wifi_config_has_credentials()) {
        ESP_LOGE(TAG, "Discovery triggered but no WiFi credentials — cannot respond");
        s_discovery_running = false;
        vTaskDelete(NULL);
        return;
    }

    ESP_LOGI(TAG, "=== Entering discovery mode ===");

    led_blink_start();
    if (!wifi_connect()) {
        ESP_LOGE(TAG, "WiFi connection failed — aborting discovery");
        led_blink_stop();
        s_discovery_running = false;
        vTaskDelete(NULL);
        return;
    }
    discovery_mdns_start();
    httpd_handle_t server = discovery_start_server();

    // Wait for confirmation or timeout
    s_confirmed = false;
    int64_t start = esp_timer_get_time();

    while (!s_confirmed) {
        vTaskDelay(pdMS_TO_TICKS(100));
        int64_t elapsed_ms = (esp_timer_get_time() - start) / 1000;
        if (elapsed_ms >= DISCOVERY_TIMEOUT_MS) {
            ESP_LOGW(TAG, "Discovery timeout — no confirmation received");
            break;
        }
    }

    // Cleanup
    if (server) {
        httpd_stop(server);
    }
    mdns_free();
    wifi_disconnect();
    led_blink_stop();

    if (s_confirmed) {
        ESP_LOGI(TAG, "=== Discovery complete — module registered ===");
    } else {
        ESP_LOGI(TAG, "=== Discovery timed out — will respond to next trigger ===");
    }

    s_discovery_running = false;
    vTaskDelete(NULL);
}

bool discovery_is_running(void)
{
    return s_discovery_running;
}

void discovery_handle_trigger(void)
{
    if (s_discovery_running) {
        ESP_LOGW(TAG, "Discovery already in progress — ignoring trigger");
        return;
    }
    if (ota_is_running()) {
        ESP_LOGW(TAG, "OTA in progress — ignoring discovery trigger");
        return;
    }
    s_discovery_running = true;
    xTaskCreate(discovery_task_fn, "discovery", 8192, NULL, 3, NULL);
}

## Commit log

2026-03-02 Switching to waveshare ESP32-C6 module given better documentation over previously purchased modules
    [TrailCurrentCabinetAndDoorSensorModuleEDA.FCStd, TrailCurrentCabinetAndDoorSensorModuleHousing.FCStd]
2026-03-08 Renamed to align with product names
    [TrailCurrentPicketModule.kicad_pcb, TrailCurrentPicketModule.kicad_sch, TrailCurrentPicketModuleEDA.FCStd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]
2026-03-26 Moving to ESP-IDF
    [partitions.csv]
2026-03-27 Additional changes for discovery fixes
    [discovery.c, main.c]
2026-03-28 Fixed bug where discovery would disrupt CAN messaging
    [discovery.c]
2026-03-28 Fixing issue with CAN Bus stops responding when discovery happens
    [main.c]
2026-04-12 Adding discovery for this device
